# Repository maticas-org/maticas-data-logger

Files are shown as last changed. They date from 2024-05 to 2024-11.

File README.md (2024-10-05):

# Maticas datalogger 🚀⭐️

Want to send measurements back to a server through HTTP or MQTT? This is about it along with:

- The PCB design 🤖.
    - The schematic.
    - The PCB layout.
    - Source files for KiCad.
- 3D design 🗿:
    - The enclosure.
    - The sensor holder, stevenson screen.
- Code for the ESP32 💻.
    - Arduino code.

### ESP32 [Bee-Data-Logger](https://github.com/strid3r21/Bee-Data-Logger) Based 🐝

The ESP32 Bee-Data-Logger based solution is a data logger based on the development from [them](https://github.com/strid3r21/Bee-Data-Logger).

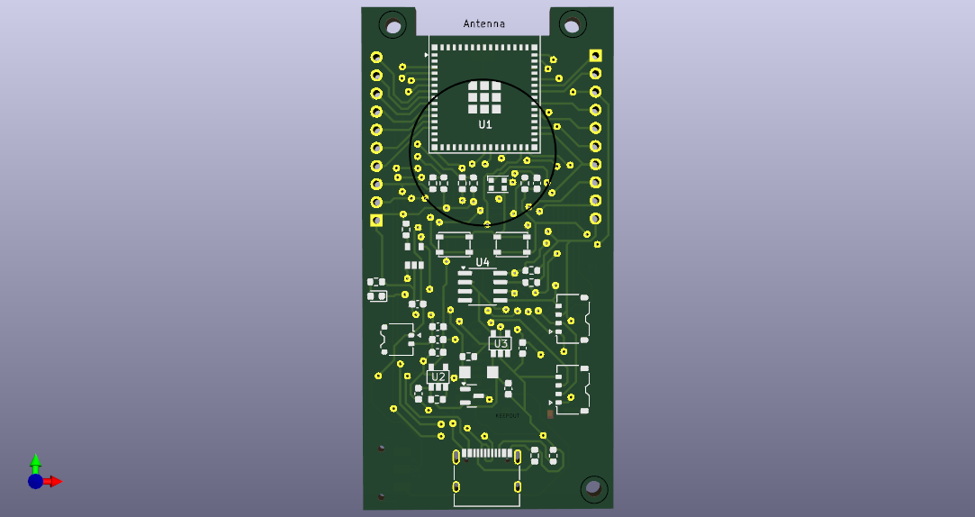
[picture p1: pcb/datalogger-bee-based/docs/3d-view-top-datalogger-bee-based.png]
Bee-Data-Logger


It is intended to be final product, we grabbed the schematic pdf they provided and made a PCB design for it, sharing the KiCad files and the Gerber files, so you can make your own PCB, or have an easier time modifying the design.

If you want to find out more about the ESP32 Bee-Data-Logger based solution, check out the [ESP32 Bee-Data-Logger based PCB design doc](/pcb/datalogger-bee-based/).

### ESP32 Dev Board 🔧

The ESP32 Dev Board is a development board with an ESP32 microcontroller. Intended for prototyping and development, but you could use it for a final product. 

If want to find out more about the ESP32 Dev Board, check out the [ESP32 Dev Board code](/src/arduino/datalogger-esp32-dev-board/) and the [ESP32 Dev Board PCB design doc](/pcb/datalogger-esp32-dev-board/).

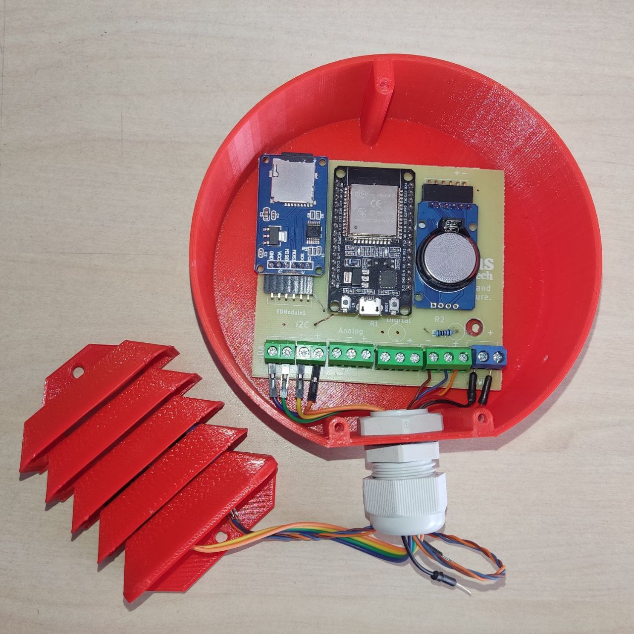
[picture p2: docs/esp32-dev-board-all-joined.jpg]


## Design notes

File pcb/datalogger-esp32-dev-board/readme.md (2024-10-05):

# ESP32 based datalogger development board

This board was designed to be a development board for the ESP32 based datalogger project. It is a simple board with capacity for few sensors and a microSD card slot, along with an RTC. This board is not meant to be a final product, but a development board to help with the development of the datalogger project, does not have a battery management system.

## Features

You can connect:

1. Multiple I2C sensors.
2. 1x Analog sensor.
3. 2x Digital sensor (with pull-up resistor).

And it has:
- MicroSD card slot.
- RTC.

## Product view 
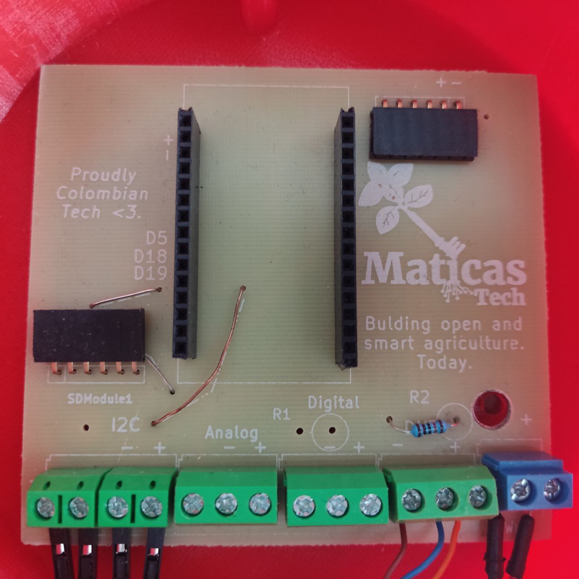
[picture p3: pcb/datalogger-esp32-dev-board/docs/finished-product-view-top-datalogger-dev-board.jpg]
Product view top

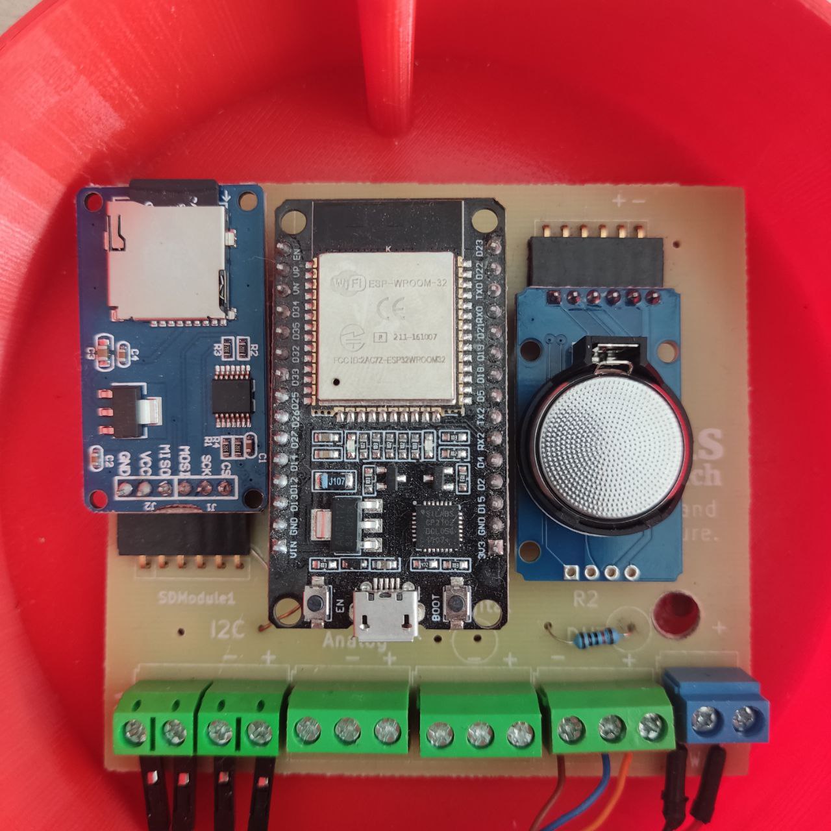
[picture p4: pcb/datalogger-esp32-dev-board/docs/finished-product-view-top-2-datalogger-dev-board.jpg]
Product view top 2


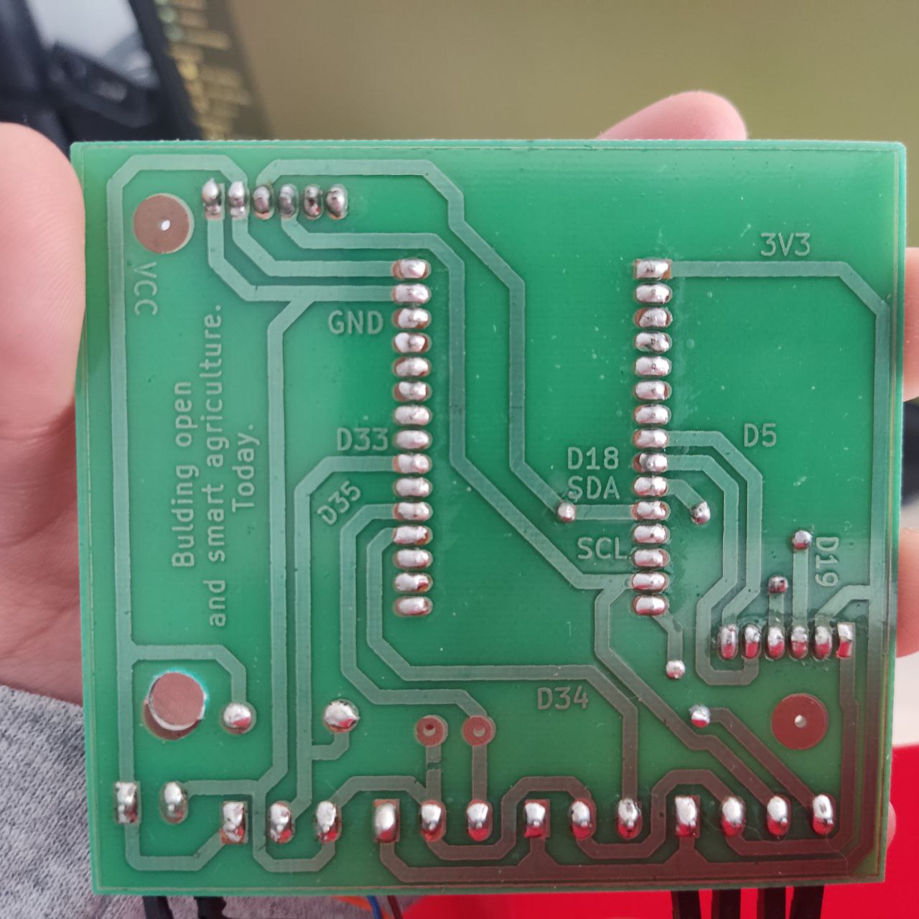
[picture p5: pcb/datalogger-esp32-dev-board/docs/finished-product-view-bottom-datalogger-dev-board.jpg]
Product view bottom


## Schematics
Schematics

## PCB Overview
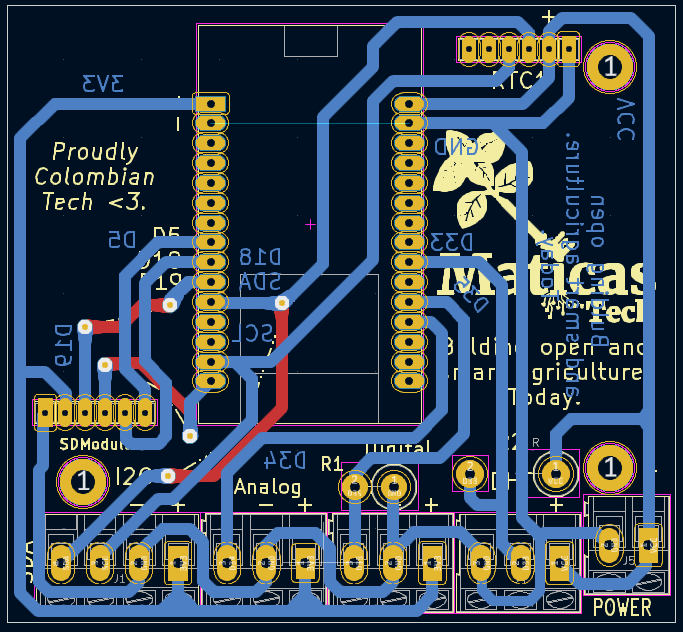
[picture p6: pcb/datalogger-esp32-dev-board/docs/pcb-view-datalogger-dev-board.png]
PCB Overview


## PCB 3D View
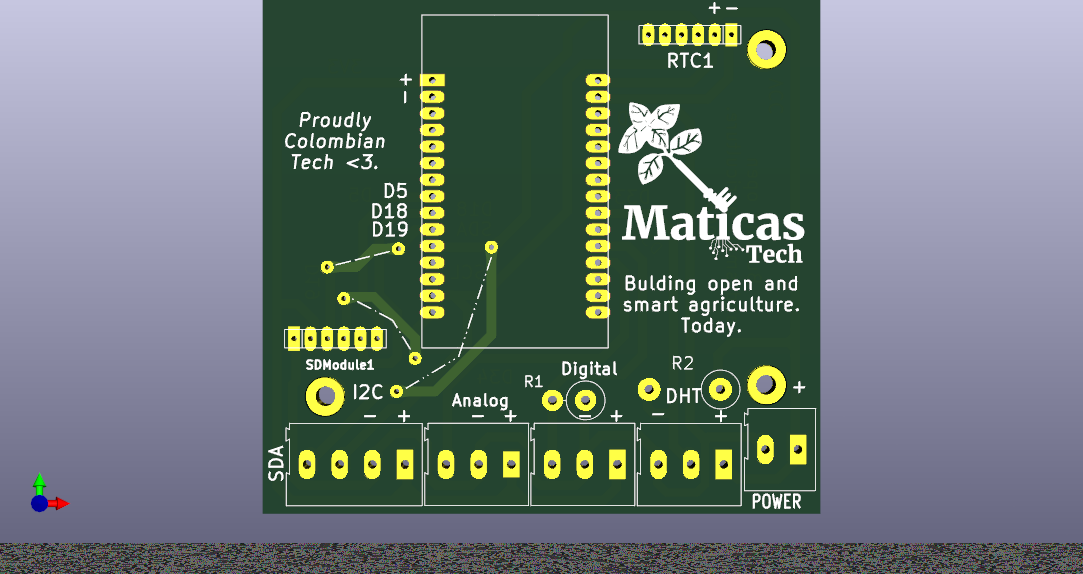
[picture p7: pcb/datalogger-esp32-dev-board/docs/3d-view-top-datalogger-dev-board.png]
PCB 3D View

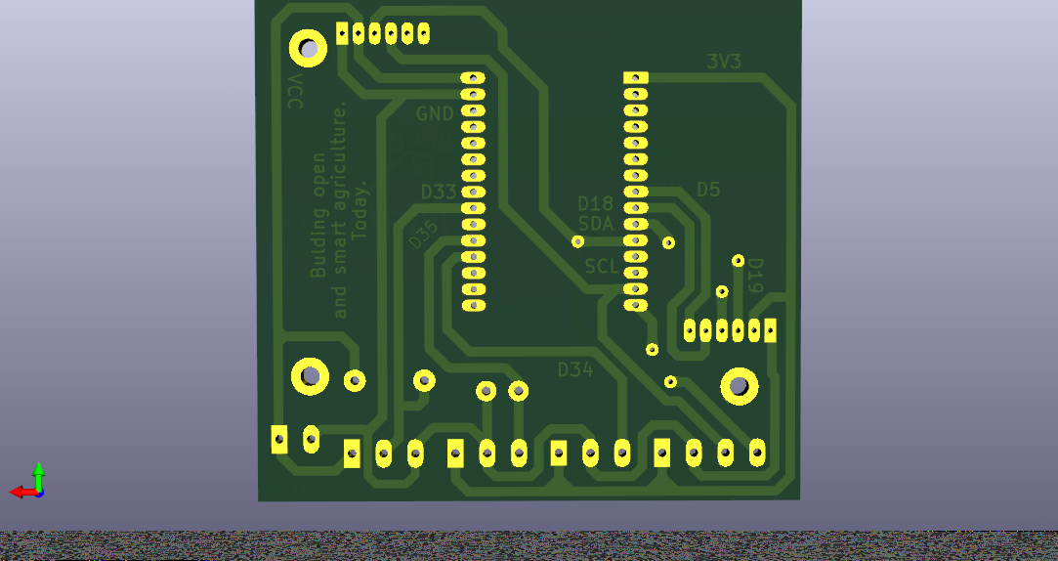
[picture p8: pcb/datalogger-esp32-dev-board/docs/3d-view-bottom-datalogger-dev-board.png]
PCB 3D View


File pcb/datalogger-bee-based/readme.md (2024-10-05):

# This file is inspired on the work of the [Bee-Data-Logger](https://github.com/strid3r21/Bee-Data-Logger) project

Basically we took the schematics they shared and a bit of the layout we get from their [youtube video](https://youtu.be/vbtSqaVAqRw?si=KjJlswMw_XBVi3_l) and we made our own version of the datalogger, sharing the source files from kiCad to make it easier for others to replicate the project.

This PCB replica is undergoing testing and will be updated as soon as we have more information.

Huge thanks to the [Bee-Data-Logger](https://github.com/strid3r21/Bee-Data-Logger) project for sharing their work, it was a great inspiration for us, and a huge help to get started with our own datalogger project. Go check their project out! Give them a star️ ⭐️⭐️⭐! 

Please consider that the latest finished PCB version is [PCB_ESP32.kicad_pro](PCB_ESP32.kicad_pro), this is built on top of Kicad 8.0. So far we don't have code along for this project, so if you are interested in replicating this project, you will need to adapt the code from the [Bee-Data-Logger](https://github.com/strid3r21/Bee-Data-Logger)

## Schematics
Schematics

## PCB Overview
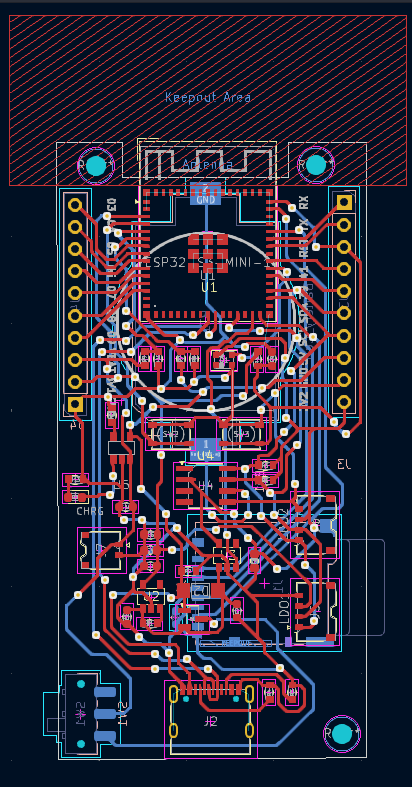
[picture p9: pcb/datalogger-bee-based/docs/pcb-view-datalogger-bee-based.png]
PCB Overview


## PCB 3D View
PCB 3D View
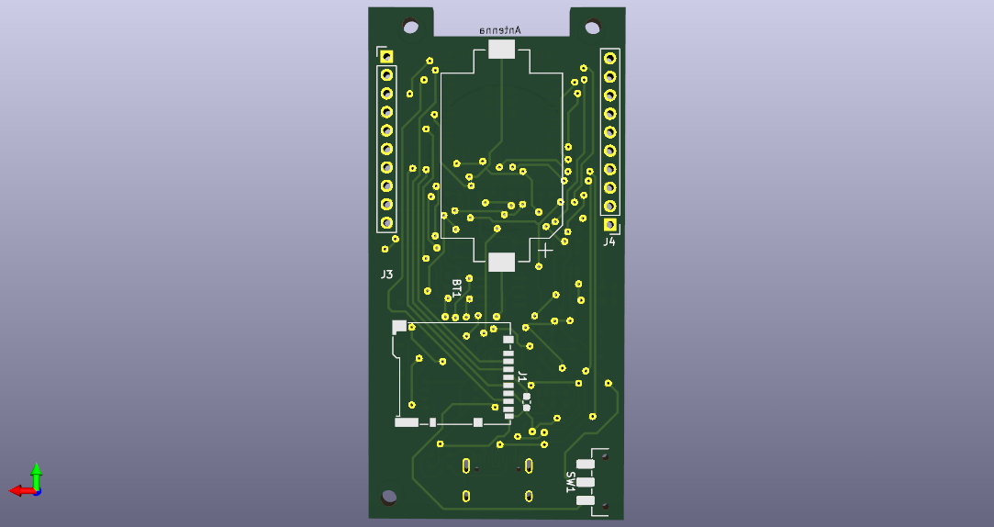
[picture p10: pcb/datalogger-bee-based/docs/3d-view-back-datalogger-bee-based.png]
PCB 3D View


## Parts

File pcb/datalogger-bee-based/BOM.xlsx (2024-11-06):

No. | Quantity | Footprint | Designator |  | Comment | Manufacturer Part | Manufacturer | Supplier Part | Supplier | Primary Category | Secondary Category | Device | Name
1 | 1 | Device_Battery_Cell | BT1 |  | 1060TR |  |  | C238069 |  |  |  | Device_Battery_Cell | Device_Battery_Cell
2 | 7 | Device_C | C1,C3,C4,C5,C6,C7,C10 |  | 10uF |  |  | C96446 |  |  |  | Device_C | Device_C
3 | 2 | Device_C | C8,C9 |  | 1uF |  |  | C15849 |  |  |  | Device_C | Device_C
4 | 1 | LED_WS2812B | D1 |  | WS2812B |  |  | C965555 |  |  |  | LED_WS2812B | LED_WS2812B
5 | 1 | Device_D_Schottky | D2 |  | ss14 |  |  | C2480 |  |  |  | Device_D_Schottky | Device_D_Schottky
6 | 1 | Device_LED | D3 |  | XL-1608SURC-06 |  |  | C965799 |  |  |  | Device_LED | Device_LED
7 | 1 | Connector_Micro_SD_Card | J1 |  | DM3BT-DSF-PEJS |  |  | C597972 |  |  |  | Connector_Micro_SD_Card | Connector_Micro_SD_Card
8 | 1 | Connector_USB_C_Receptacle_USB2.0_16P | J2 |  | U262-161N-4BVC11 |  |  | C319148 |  |  |  | Connector_USB_C_Receptacle_USB2.0_16P | Connector_USB_C_Receptacle_USB2.0_16P
9 | 2 | Connector_Conn_01x10_Socket | J3,J4 |  | Conn_01x10_Socket |  |  | C2894933 |  |  |  | Connector_Conn_01x10_Socket | Connector_Conn_01x10_Socket
10 | 2 | Connector_Conn_01x05_Socket | J5,J6 |  | Conn_01x05_Socket |  |  | C528030 |  |  |  | Connector_Conn_01x05_Socket | Connector_Conn_01x05_Socket
11 | 1 | Connector_Generic_Conn_01x02 | J7 |  | Conn_01x02 |  |  | C202104 |  |  |  | Connector_Generic_Conn_01x02 | Connector_Generic_Conn_01x02
12 | 1 | Transistor_FET_AO3401A | Q1 |  | DMP2045UQ |  |  | C3290014 |  |  |  | Transistor_FET_AO3401A | Transistor_FET_AO3401A
13 | 4 | Device_R | R1,R2,R12,R13 |  | 100K |  |  | C25803 |  |  |  | Device_R | Device_R
14 | 3 | Device_R | R3,R4,R11 |  | 5.1K |  |  | C23186 |  |  |  | Device_R | Device_R
15 | 6 | Device_R | R5,R6,R7,R8,R9,R10 |  | 3.3K |  |  | C22978 |  |  |  | Device_R | Device_R
16 | 1 | Switch_SW_DPDT_x2 | SW1 |  | SW_DPDT_x2 |  |  | C221660 |  |  |  | Switch_SW_DPDT_x2 | Switch_SW_DPDT_x2
17 | 2 | Switch_SW_MEC_5E | SW2,SW3 |  | SW_MEC_5E |  |  | C221896 |  |  |  | Switch_SW_MEC_5E | Switch_SW_MEC_5E
18 | 1 | RF_Module_ESP32-S3-MINI-1 | U1 | BULETM-SMD_ESP32-S3-MINI-1-N8 | ESP32-S3-MINI-1-N8 |  |  | C2913206 |  |  |  | RF_Module_ESP32-S3-MINI-1 | RF_Module_ESP32-S3-MINI-1
19 | 1 | Bee-Data-Logger-library_rt9080-33GJ5 | U2 |  | RT9080-33GJ5 |  |  | C2959864 |  |  |  | Bee-Data-Logger-library_rt9080-33GJ5 | Bee-Data-Logger-library_rt9080-33GJ5
20 | 1 | Bee-Data-Logger-library_rt9080-33GJ5 | U3 |  | RT9080-33GJ5 |  |  | C841192 |  |  |  | Bee-Data-Logger-library_rt9080-33GJ5 | Bee-Data-Logger-library_rt9080-33GJ5
21 | 1 | Timer_RTC_DS3231MZ | U4 |  | DS3231MZ |  |  | C107410 |  |  |  | Timer_RTC_DS3231MZ | Timer_RTC_DS3231MZ
22 | 1 | Bee-Data-Logger-library_MCP73831/2 | U5 |  | MCP73831/2 |  |  | C625597 |  |  |  | Bee-Data-Logger-library_MCP73831/2 | Bee-Data-Logger-library_MCP73831/2

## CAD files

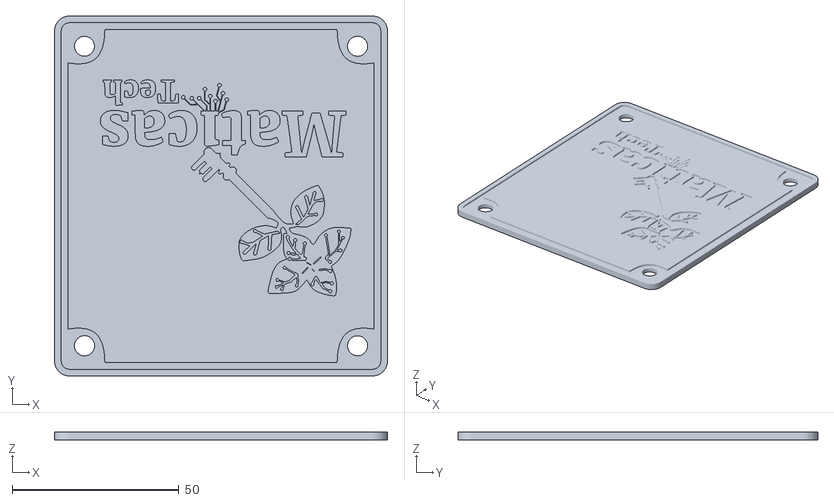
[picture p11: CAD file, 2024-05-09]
3d-printing/box/datalogger-waterproof-box-cap.stl
100.0 x 108.1 x 2.50

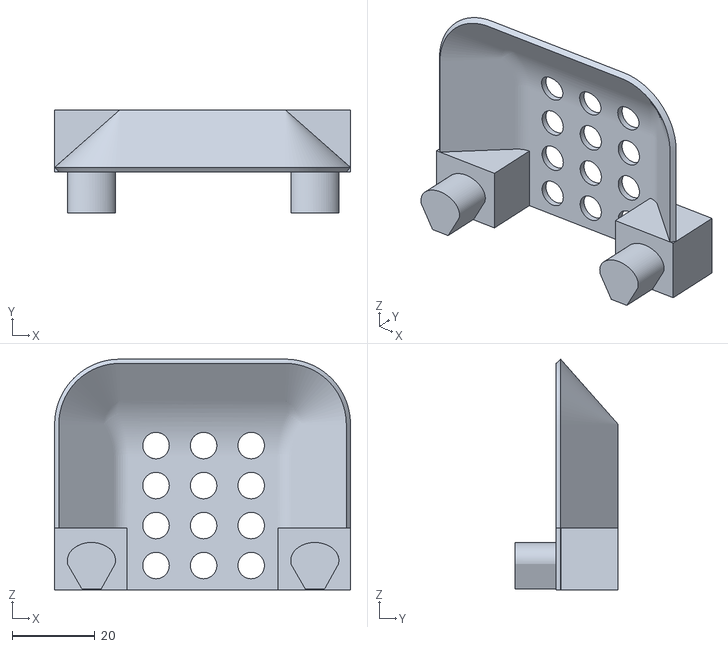
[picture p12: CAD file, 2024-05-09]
3d-printing/stevenson-screen/stevenson-screen-nivel-intermedio-v5.stl
71.5 x 25.0 x 55.8

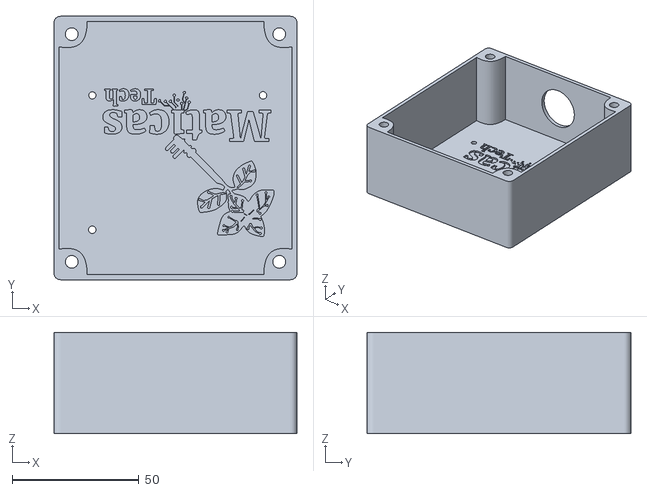
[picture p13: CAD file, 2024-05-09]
3d-printing/box/datalogger-waterproof-box-body.stl
96.0 x 104.1 x 40.0

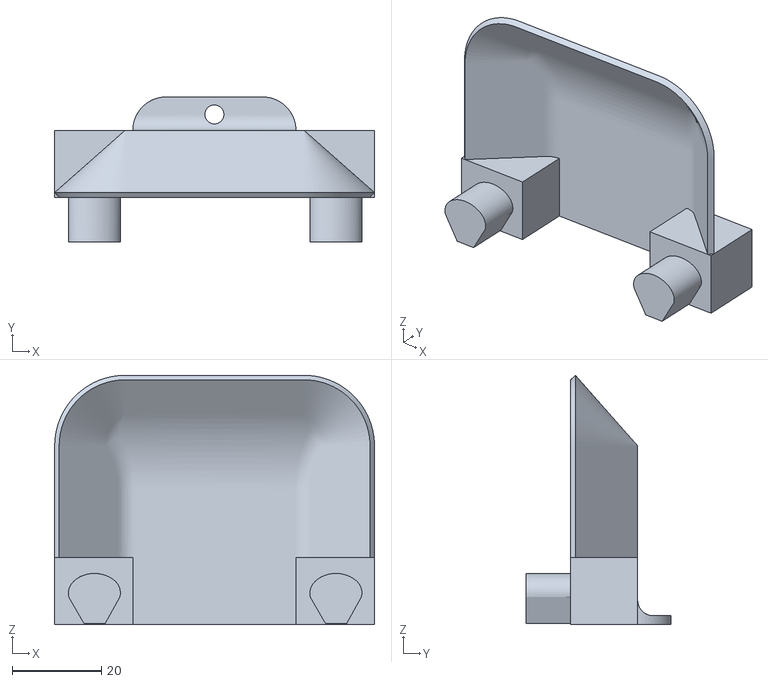
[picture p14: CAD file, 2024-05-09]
3d-printing/stevenson-screen/stevenson-screen-techo-v5.stl
71.5 x 32.5 x 55.8

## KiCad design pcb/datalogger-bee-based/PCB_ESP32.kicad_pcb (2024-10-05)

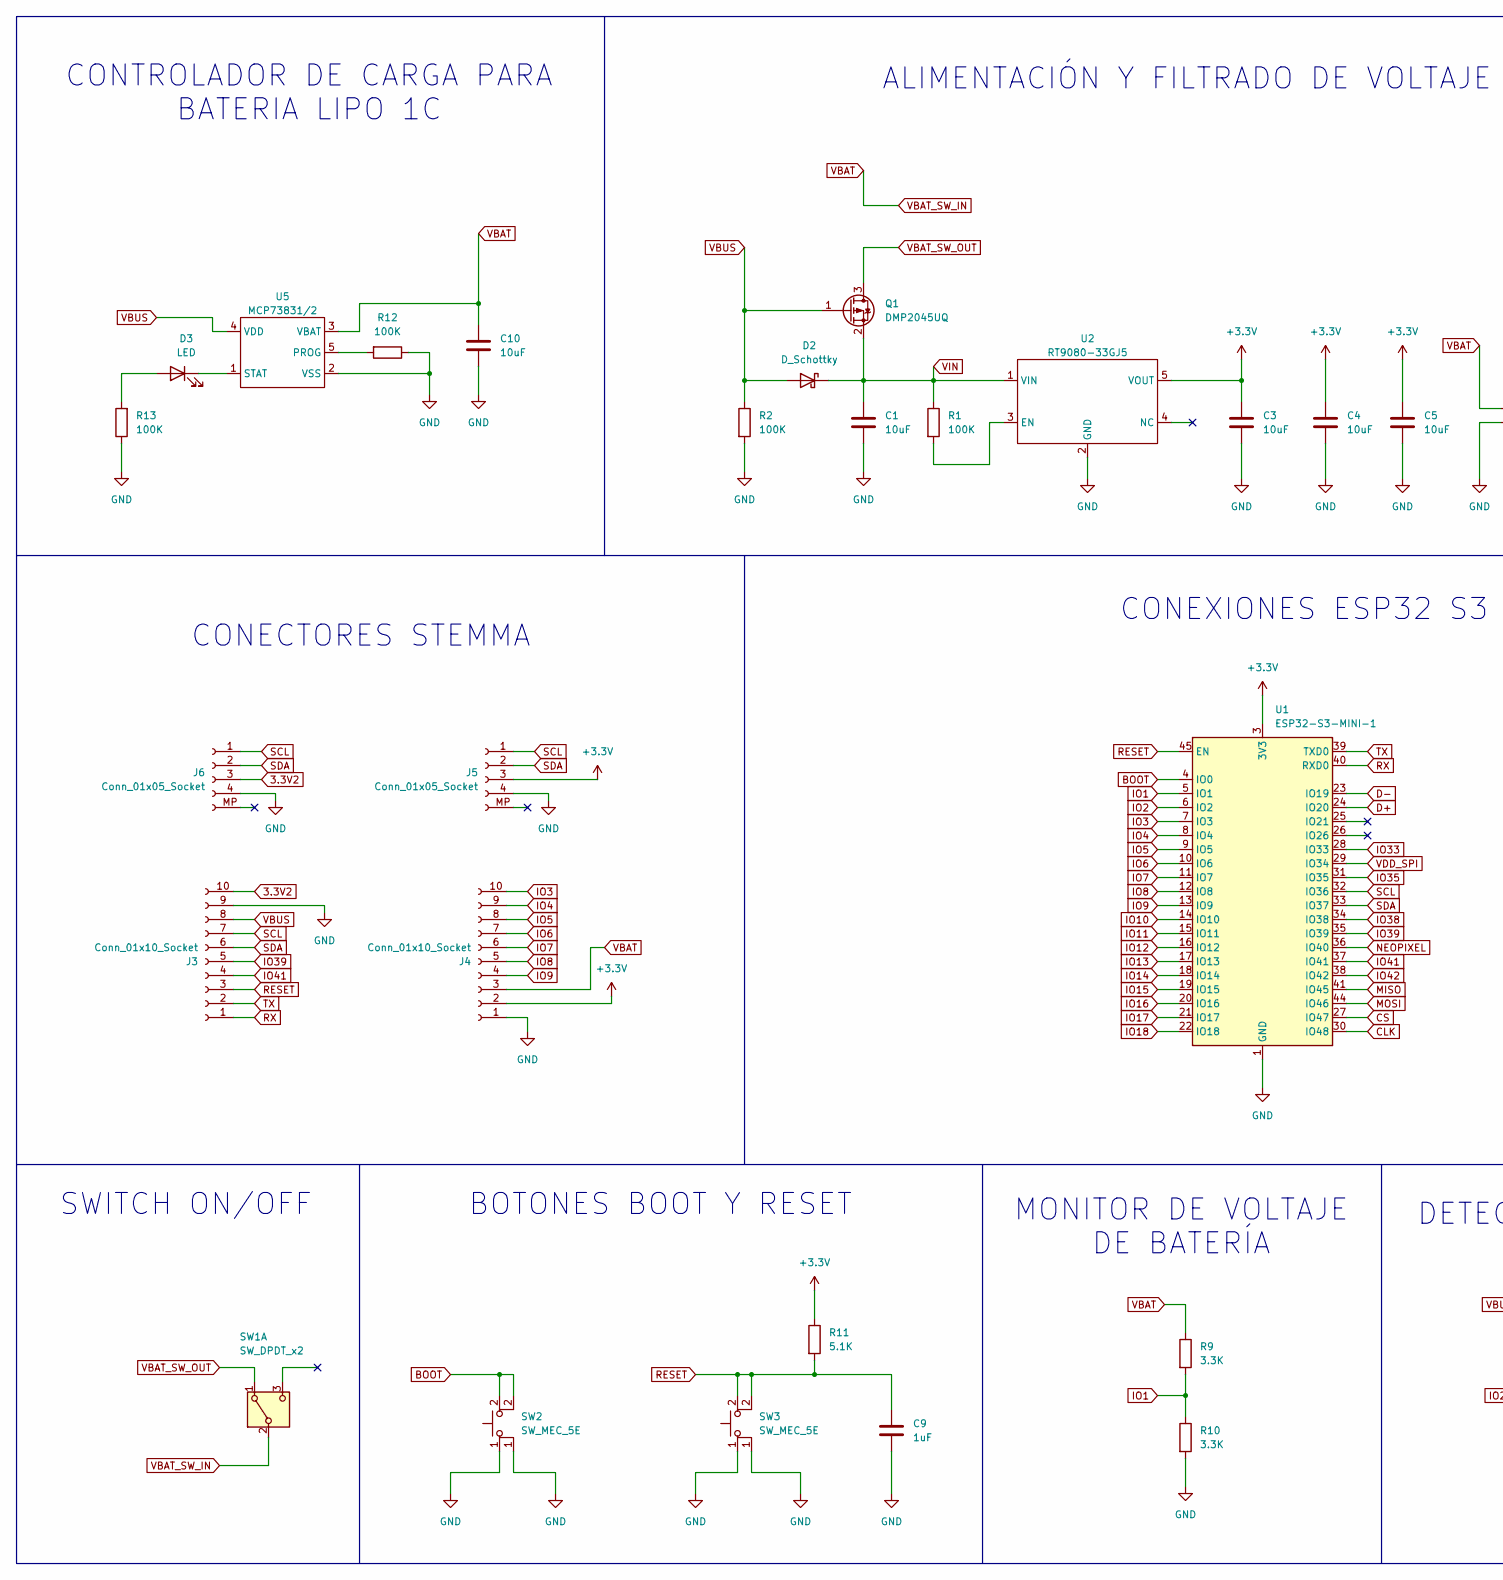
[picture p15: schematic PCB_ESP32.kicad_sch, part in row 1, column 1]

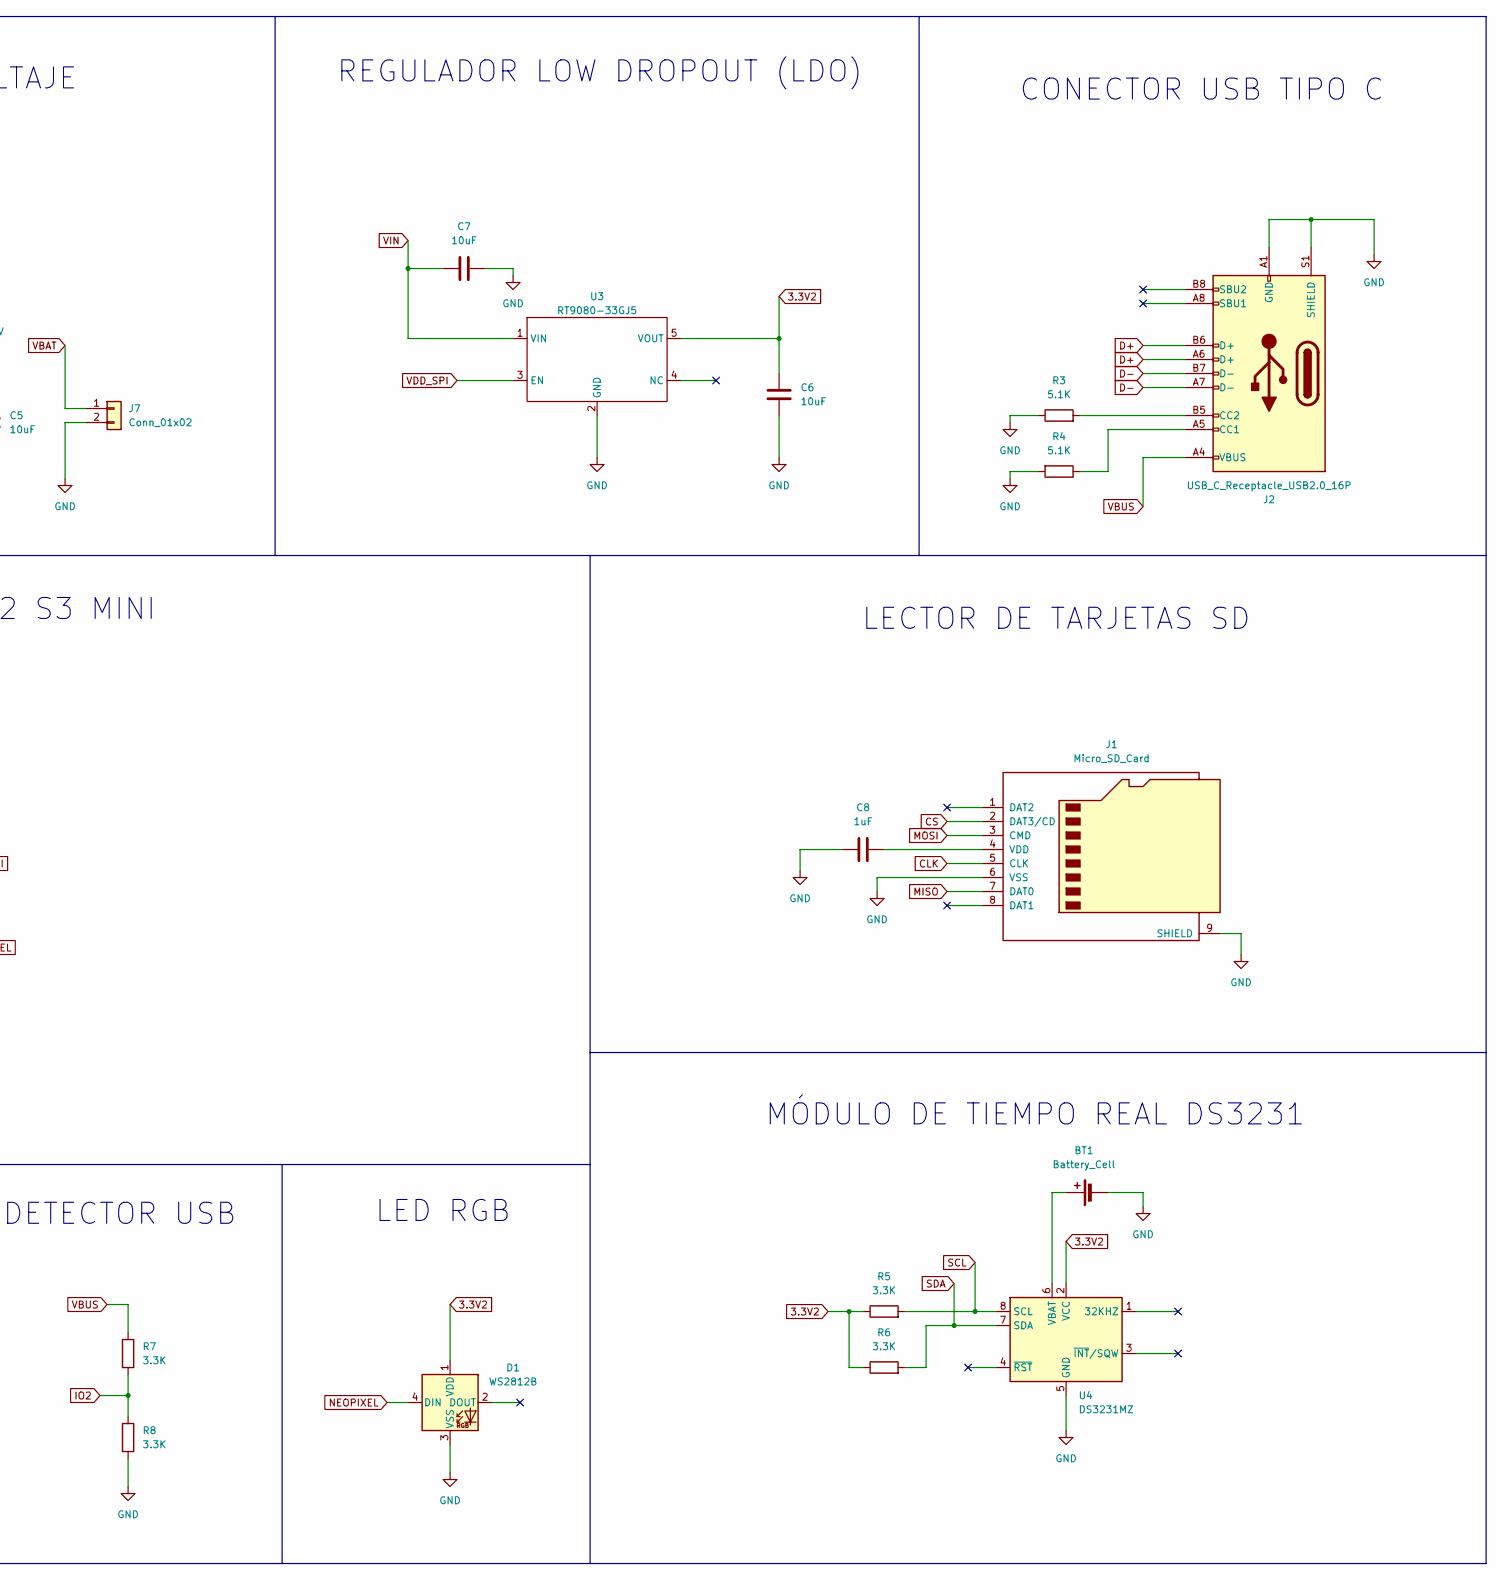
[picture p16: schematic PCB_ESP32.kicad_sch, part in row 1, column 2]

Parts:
BT1: Battery_Cell; BatteryHolder_Keystone_1060_1x2032
C1, C3, C4, C5, C6, C7, C10: 10uF; C_0603_1608Metric
C8, C9: 1uF; C_0603_1608Metric
D1: WS2812B; LED_WS2812B-2020_PLCC4_2.0x2.0mm
D2: D_Schottky; DO-214AC
D3: LED; LED_0603_1608Metric
J1: Micro_SD_Card; microSD_HC_Hirose_DM3BT-DSF-PEJS
J2: USB_C_Receptacle_USB2.0_16P; USB_C_Receptacle_XKB_U262-16XN-4BVC11
J3, J4: Conn_01x10_Socket; PinHeader_1x10_P2.54mm_Vertical
J5, J6: Conn_01x05_Socket; JST_ACH_BM04B-ACHSS-A-GAN-ETF_1x04-1MP_P1.20mm_Vertical
J7: Conn_01x02; JST_ACH_BM02B-ACHSS-GAN-ETF_1x02-1MP_P1.20mm_Vertical
Q1: DMP2045UQ; SOT-23
R1, R2, R12, R13: 100K; R_0603_1608Metric
R3, R4, R11: 5.1K; R_0603_1608Metric
R5, R6, R7, R8, R9, R10: 3.3K; R_0603_1608Metric
SW1: SW_DPDT_x2; SW_SPDT_CK_JS102011SAQN
SW2, SW3: SW_MEC_5E; SW_SPST_PTS810
U1: ESP32-S3-MINI-1; ESP32-S2-MINI-1
U2, U3: RT9080-33GJ5; TSOT-23-5
U4: DS3231MZ; SOIC-8_3.9x4.9mm_P1.27mm
U5: MCP73831/2; SOT-23-5

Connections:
3.3V2: C6.1, D1.1 (VDD), J3.10, J6.3, R5.1, R6.1, U3.5 (VOUT), U4.2 (VCC)
+3.3V: C3.1, C4.1, C5.1, J4.2, J5.3, R11.1, U1.3 (3V3), U2.5 (VOUT)
BOOT: SW2.2, U1.4 (IO0)
CLK: J1.5 (CLK), U1.30 (IO48)
CS: J1.2 (DAT3/CD), U1.27 (IO47)
D+: J2.A6 (D+), J2.B6 (D+), U1.24 (IO20)
D-: J2.A7 (D-), J2.B7 (D-), U1.23 (IO19)
GND: BT1.2 (-), C1.2, C3.2, C4.2, C5.2, C6.2, C7.2, C8.1, C9.2, C10.2, D1.3 (VSS), J1.6 (VSS), J1.9 (SHIELD), J2.A1 (GND), J2.A12 (GND), J2.B1 (GND), J2.B12 (GND), J2.S1 (SHIELD), J3.9, J4.1, J5.4, J6.4, J7.2, R2.2, R3.1, R4.2, R8.2, R10.2, R12.1, R13.1, SW2.1, SW3.1, U1.1 (GND), U1.2 (GND), U1.42 (GND), U1.43 (GND), U1.46 (GND), U1.47 (GND), U1.48 (GND), U1.49 (GND), U1.50 (GND), U1.51 (GND), U1.52 (GND), U1.53 (GND), U1.54 (GND), U1.55 (GND), U1.56 (GND), U1.57 (GND), U1.58 (GND), U1.59 (GND), U1.60 (GND), U1.61 (GND), U1.62 (GND), U1.63 (GND), U1.64 (GND), U1.65 (GND), U2.2 (GND), U3.2 (GND), U4.5 (GND), U5.2 (VSS)
IO1: R9.2, R10.1, U1.5 (IO1)
IO2: R7.2, R8.1, U1.6 (IO2)
IO3: J4.10, U1.7 (IO3)
IO4: J4.9, U1.8 (IO4)
IO5: J4.8, U1.9 (IO5)
IO6: J4.7, U1.10 (IO6)
IO7: J4.6, U1.11 (IO7)
IO8: J4.5, U1.12 (IO8)
IO9: J4.4, U1.13 (IO9)
IO10: U1.14 (IO10)
IO11: U1.15 (IO11)
IO12: U1.16 (IO12)
IO13: U1.17 (IO13)
IO14: U1.18 (IO14)
IO15: U1.19 (IO15)
IO16: U1.20 (IO16)
IO17: U1.21 (IO17)
IO18: U1.22 (IO18)
IO33: U1.28 (IO33)
IO35: U1.31 (IO35)
IO38: U1.34 (IO38)
IO39: J3.5, U1.35 (IO39)
IO41: J3.4, U1.37 (IO41)
IO42: U1.38 (IO42)
MISO: J1.7 (DAT0), U1.41 (IO45)
MOSI: J1.3 (CMD), U1.44 (IO46)
NEOPIXEL: D1.4 (DIN), U1.36 (IO40)
unnamed: BT1.1 (+), U4.6 (VBAT)
unnamed: D3.2 (A), R13.2
unnamed: D3.1 (K), U5.1 (STAT)
unnamed: C8.2, J1.4 (VDD)
unnamed: J2.A5 (CC1), R4.1
unnamed: J2.B5 (CC2), R3.2
unnamed: R1.2, U2.3 (EN)
unnamed: R12.2, U5.5 (PROG)
RESET: C9.1, J3.3, R11.2, SW3.2, U1.45 (EN)
RX: J3.1, U1.40 (RXD0)
SCL: J3.7, J5.1, J6.1, R5.2, U1.32 (IO36), U4.8 (SCL)
SDA: J3.6, J5.2, J6.2, R6.2, U1.33 (IO37), U4.7 (SDA)
TX: J3.2, U1.39 (TXD0)
VBAT: C10.1, J4.3, J7.1, R9.1, SW1.2 (B), U5.3 (VBAT)
VBAT_SW_OUT: Q1.3 (D), SW1.1 (A)
VBUS: D2.2 (A), J2.A4 (VBUS), J2.A9 (VBUS), J2.B4 (VBUS), J2.B9 (VBUS), J3.8, Q1.1 (G), R2.1, R7.1, U5.4 (VDD)
VDD_SPI: U1.29 (IO34), U3.3 (EN)
VIN: C1.1, C7.1, D2.1 (K), Q1.2 (S), R1.1, U2.1 (VIN), U3.1 (VIN)

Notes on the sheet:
LED RGB
CONEXIONES ESP32 S3 MINI
CONECTORES STEMMA
MONITOR DE VOLTAJE DE BATERÍA
LECTOR DE TARJETAS SD
SWITCH ON/OFF
ALIMENTACIÓN Y FILTRADO DE VOLTAJE
BOTONES BOOT Y RESET
DETECTOR USB
MÓDULO DE TIEMPO REAL DS3231
CONECTOR USB TIPO C
CONTROLADOR DE CARGA PARA BATERIA LIPO 1C
REGULADOR LOW DROPOUT (LDO)

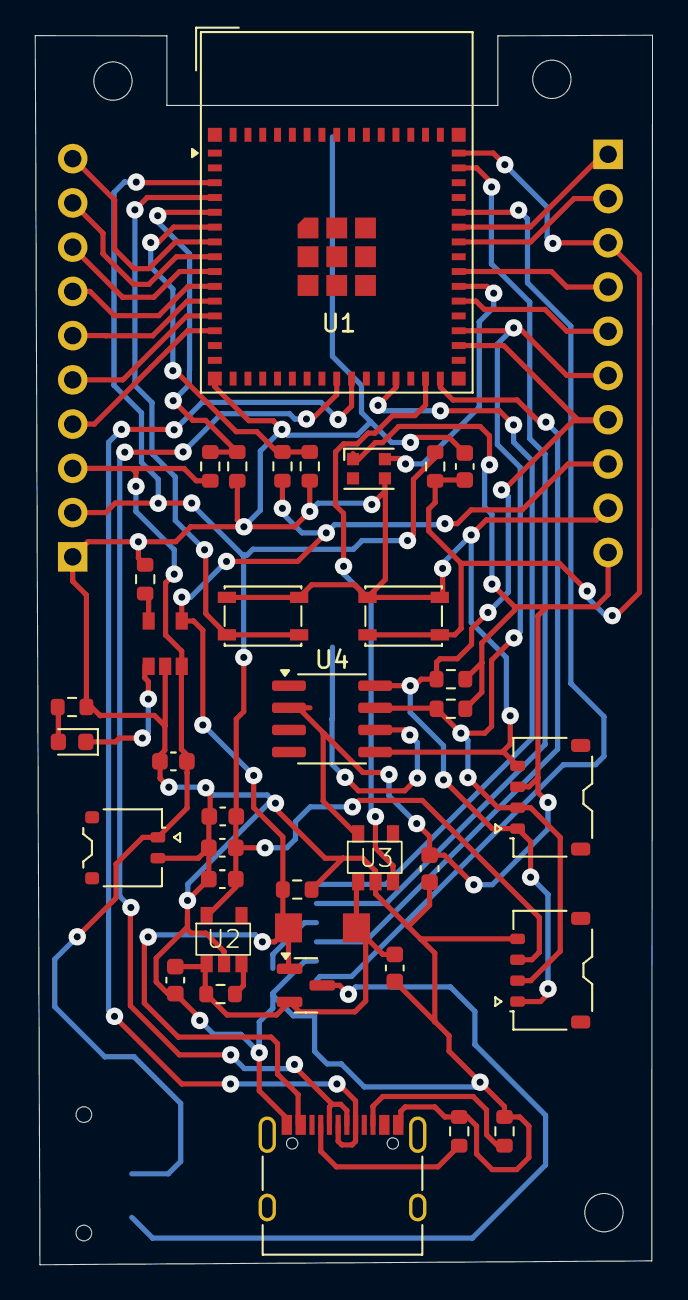
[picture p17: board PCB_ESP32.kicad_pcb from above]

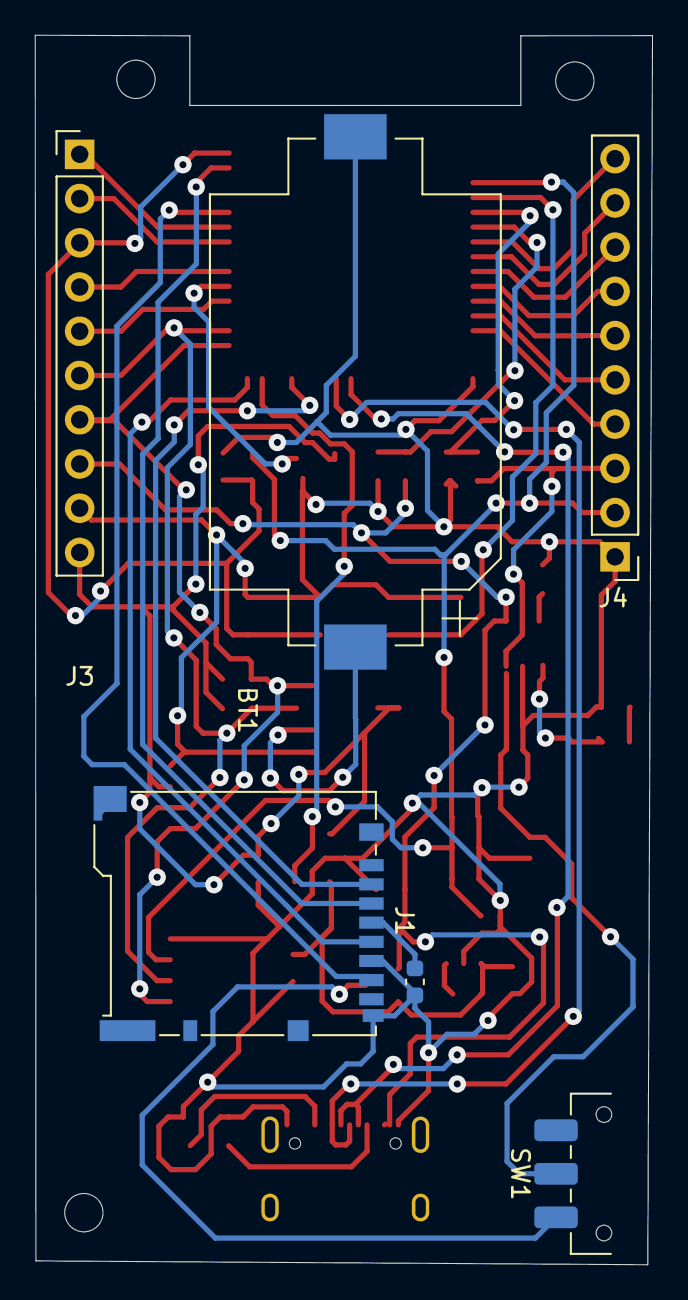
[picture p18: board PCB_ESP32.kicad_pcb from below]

Board: 2 copper layers, 35.4 x 70.6 mm, 42 parts (6 on the bottom side), 40 nets.

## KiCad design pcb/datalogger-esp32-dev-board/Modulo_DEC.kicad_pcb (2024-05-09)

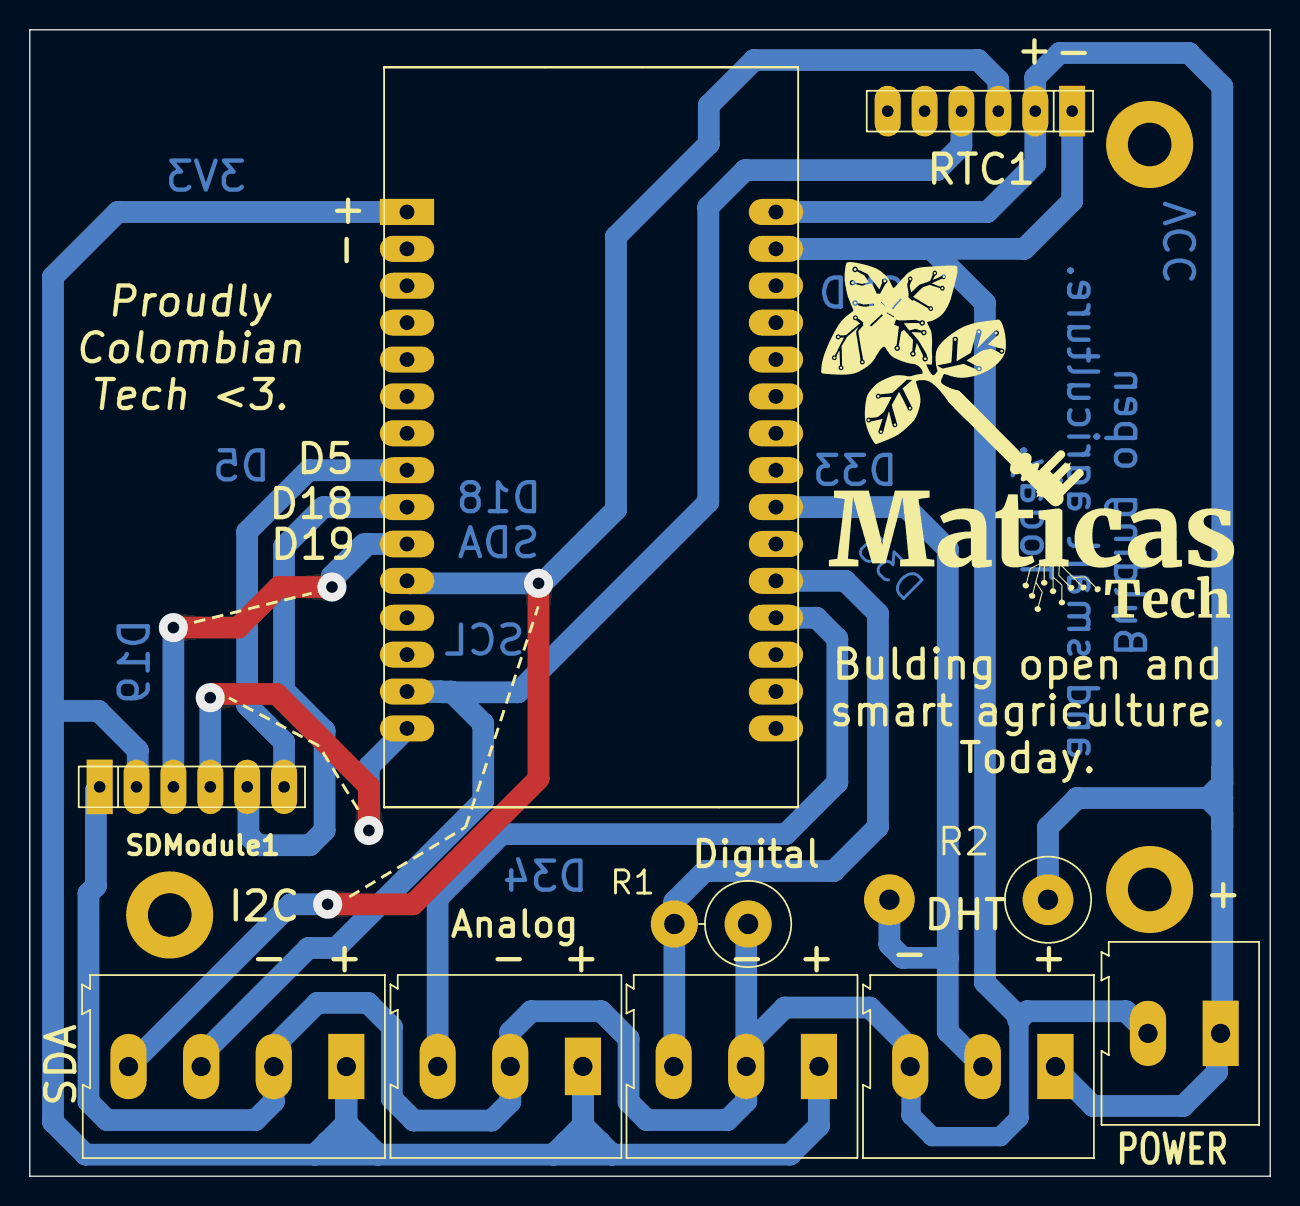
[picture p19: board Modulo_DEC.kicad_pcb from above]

Board: 2 copper layers, 85.4 x 78.9 mm, 13 parts (0 on the bottom side), 12 nets.

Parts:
H1, H2, H3: MountingHole; MountingHole_3mm_Pad
J1: Screw_Terminal_01x04; TerminalBlock_Altech_AK300-4_P5.00mm
J2, J3, J4: Screw_Terminal_01x03; TerminalBlock_Altech_AK300-3_P5.00mm
J5: Screw_Terminal_01x02; TerminalBlock_Altech_AK300-2_P5.00mm
R1, R2: R; R_Axial_DIN0614_L14.3mm_D5.7mm_P5.08mm_Vertical
RTC1: R_Array_SIP6
SDModule1: R_Network_Dividers_x04_SIP; R_Array_SIP6
U1: ESP32-DEVKIT-V1; MODULE_ESP32_DEVKIT_V1

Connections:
3V3: J1.1, J2.1, J3.1, SDModule1.2 (R1), U1.1 (3V3)
D5: SDModule1.6 (COM2), U1.8 (D5)
D18: SDModule1.5 (R4), U1.9 (D18)
D19: SDModule1.3 (R2), U1.10 (D19)
D23: SDModule1.4 (R3), U1.15 (D23)
D33: J4.2, R2.2, U1.22 (D33)
D34: J2.3, U1.19 (D34)
D35: J3.3, R1.2, U1.20 (D35)
GND: J1.2, J2.2, J3.2, J4.3, J5.2, R1.1, RTC1.1 (COM1), SDModule1.1 (COM1), U1.2 (GND), U1.29 (GND)
SCL: J1.3, RTC1.4 (R3), U1.14 (D22)
SDA: J1.4, RTC1.3 (R2), U1.11 (D21)
VCC: J4.1, J5.1, R2.1, RTC1.2 (R1), U1.30 (VIN)

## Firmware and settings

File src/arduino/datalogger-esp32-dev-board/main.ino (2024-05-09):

#ifndef EXT_IMPORTS
#define EXT_IMPORTS
  #include "FS.h"
  #include "SD.h"
  #include "SPI.h"
  #include "WiFi.h"
  #include "I2C_RTC.h"
  #include <Arduino.h>
  #include <ArduinoHttpClient.h>
#endif


#include "EventManager.h"
#include "TimeEventManager.h"
#include "ConnectionEventManager.h"

#include "CustomUtils.h"
#include "secrets.h"
#include "SensorAdapters.h"
#include "SensorsMicroService.h"

//SD card
bool sdCardInitialized = false;

//time in seconds
#define timeEventManagerFrequency 5              //5 seconds
#define sensorsMicroServiceFrequency 10*1        //2 minutes
#define connectionEventManagerFrequency 41*1    //10 minutes
#define sdStoreFrequency 60*2                    //11 minutes
#define sdLoadFrequency 60*1                     //12 minutes
#define LED 2

void updateEventManager(EventManager &eventManager, unsigned long &previousEventMillis, unsigned long &currentMillis, unsigned long eventFrequency);
void sendPendingAndStoreExcessEvents(ConnectionEventManager &connectioneventmanager, TimeEventManager &timeeventmanager);
void loadAndSendEvents(ConnectionEventManager &connectionEventManager, bool fromNewestToOldest = true);

void setup() {

  //initialize the serial port, the i2c bus, the spi bus
  Serial.begin(9600);
  delay(250);
  Wire.begin();
  delay(250);
  SPI.begin(SCK, MISO, MOSI, CS);
  delay(250);

  //initialize the LED
  pinMode(LED, OUTPUT);
  digitalWrite(LED, HIGH);
  delay(1000);
  digitalWrite(LED, LOW);

  // start the SD card
  if(!SD.begin()){
      Serial.println("Card Mount Failed");
  }else{
      Serial.println("Card Mount Success");
      sdCardInitialized = true;
  }

  showAditionalSDCardInfo(SD);
}

void loop() {

  delay(100);
  TimeEventManager timeEventManager = TimeEventManager(timeEventManagerFrequency);
  ConnectionEventManager connectionEventManager;
  SensorsMicroService sensorsMicroService = SensorsMicroService();
  DHTAdapter dhtAdapter = DHTAdapter();
  LuxAndDLIAdapter luxAndDLIAdapter = LuxAndDLIAdapter(connectionEventManagerFrequency);

  sensorsMicroService.AddSensor(&dhtAdapter);
  sensorsMicroService.AddSensor(&luxAndDLIAdapter);

  timeEventManager.subscribe(&sensorsMicroService);
  sensorsMicroService.subscribe(&connectionEventManager);
  delay(100);
  logMemoryUsage();
  connectionEventManager.main();
  logMemoryUsage();

  unsigned long previousTimeEventMillis = 0;
  unsigned long previousConnectionEventMillis = 0;
  unsigned long previousSensorsMicroServiceMillis = 0;
  unsigned long sdStoreMillis = 0;
  unsigned long sdLoadMillis = 0;
  unsigned long currentMillis = millis();

  while (true) {
    currentMillis = millis();
    
    //update the time
    updateEventManager(timeEventManager, previousTimeEventMillis, currentMillis, timeEventManagerFrequency);
    
    //update the connection - this tries to connect to the wifi and check if the connection
    //is still alive
    updateEventManager(connectionEventManager, previousConnectionEventMillis, currentMillis, connectionEventManagerFrequency);

    //update the time
    updateEventManager(timeEventManager, previousTimeEventMillis, currentMillis, timeEventManagerFrequency);

    //update the measurements from sensors - this tries to get the measurements from
    //the sensors and notify the subscribers
    updateEventManager(sensorsMicroService, previousSensorsMicroServiceMillis, currentMillis, sensorsMicroServiceFrequency);

    //update the time
    updateEventManager(timeEventManager, previousTimeEventMillis, currentMillis, timeEventManagerFrequency);

    //send pending events and store excess events
    sendPendingAndStoreExcessEvents(connectionEventManager, timeEventManager);

    //load and send events from the SD card
    loadAndSendEvents(connectionEventManager);

    //show memory usage
    logMemoryUsage();
    delay(2500);
  }

}



/*
* Update the event manager
*/
void updateEventManager(EventManager &eventManager,
                        unsigned long &previousEventMillis,
                        unsigned long &currentMillis,
                        unsigned long eventFrequency) {
  if (currentMillis - previousEventMillis >= eventFrequency * 1000) {
    eventManager.notify();
    previousEventMillis = currentMillis;
  }
  currentMillis = millis();
}

void sendPendingAndStoreExcessEvents(ConnectionEventManager &connectionEventManager, 
                                     TimeEventManager &timeEventManager){
  
  String epoch = String(abs(timeEventManager.getEpoch()));
  String fileName = "/" + epoch + ".txt";

  // try to send any pending events
  connectionEventManager.sendMemAllocatedData();

  // store excess pending events in the SD card
  Event excessEvents[MAX_EVENTS_PER_FILE];
  bool availableData = connectionEventManager.returnExcessEvents(excessEvents, MAX_EVENTS_PER_FILE);
  if (availableData) {
    storeEvents(SD, excessEvents, MAX_EVENTS_PER_FILE, fileName.c_str());
  }
}

void loadAndSendEvents(ConnectionEventManager &connectionEventManager, 
                       bool fromNewestToOldest) {
  Event loadedEvents[MAX_EVENTS_PER_FILE];
  String filename = "/" + findFileByDate(SD, "/", fromNewestToOldest);
  bool loadedData = loadEvents(SD, loadedEvents, MAX_EVENTS_PER_FILE, filename.c_str());

  if (loadedData) {
    bool allSent = connectionEventManager.updateFromLoadedEvents(loadedEvents, MAX_EVENTS_PER_FILE);
    //if all events were sent, delete the file, otherwise store the remaining events
    if (allSent) {
      deleteFile(SD, filename.c_str());
    }else{
      storeEvents(SD, loadedEvents, MAX_EVENTS_PER_FILE, filename.c_str());
    }
  }
}

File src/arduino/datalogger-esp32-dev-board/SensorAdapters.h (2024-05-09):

#include "DHT.h"
#include <BH1750.h>

#include "secrets.h"
#include "Event.h"
#include "Adapter.h"
#include "CustomUtils.h"

#define DHTPIN 33
#define DHTTYPE DHT11
#define MAX_RETRIES 5

DHT dht = DHT(DHTPIN, DHTTYPE);
BH1750 lightMeter;
const double lux2parConversionFactor = 0.0185; // Conversion factor from lux to PAR

//--------------------HELPER FUNCTIONS--------------------

float average(float values[], int size)
{
    if (size == 0)
    {
        return 0;
    }

    float sum = 0;
    for (int i = 0; i < size; i++)
    {
        sum += values[i];
    }
    return sum / size;
}

bool isvalid(float value)
{
    return !isnan(value) && !isinf(value) && value >= 0;
}

/***************** Vapour Pressur Deficit in kPa ********************/
float calculateSaturationVaporPressure(float temperature)
{
    return 0.6108 * exp((17.27 * temperature) / (temperature + 237.3));
}

float calculateVPD(float temperature, float relativeHumidity)
{
    float saturationVaporPressure = calculateSaturationVaporPressure(temperature);
    return (1.0 - (relativeHumidity / 100.0)) * saturationVaporPressure; // kPa
}

/***************** Dew point in °C ********************/
// Magnus coefficients
const float a = 17.625;
const float b = 243.04;

// Function to calculate the Magnus-Tetens intermediate value alpha
float calculateAlpha(float temperature, float relativeHumidity)
{
    return log(relativeHumidity / 100.0) + (a * temperature) / (b + temperature);
}

// Function to calculate Dew Point (Ts) using the Magnus-Tetens formula
float calculateDewPoint(float temperature, float relativeHumidity)
{
    float alpha = calculateAlpha(temperature, relativeHumidity);
    return (b * alpha) / (a - alpha);
}

//--------------------ADAPTERS--------------------
class DHTAdapter : public Adapter
{
private:
    Event (*specificRequestFunc)() = nullptr;
    int maxRetries;
    int retryDelay;
    long int lastRequestTimestamp = -1;

public:
    DHTAdapter(int maxRetries = 5, int retryDelay = 2100) : Adapter()
    {
        dht.begin();
        this->maxRetries = maxRetries;
        this->retryDelay = retryDelay;
    }

    Event request(Event timeEvent)
    {
        Serial.println("DHTAdapter handling request...");
        return specificRequest(timeEvent);
    }

    Event specificRequest(Event timeEvent)
    {
        // Run specific request function if it is set
        // Otherwise, run the default request function
        if (specificRequestFunc != nullptr)
        {
            return specificRequestFunc();
        }
        else
        {
            return default_request(timeEvent);
        }
    }

    Event default_request(Event timeEvent)
    {
        float temperatureArray[maxRetries];
        float humidityArray[maxRetries];

        try
        {
            dht.begin();
            int validReadings = 0;

            for (int i = 0; i < maxRetries; i++)
            {
                float humidity = dht.readHumidity();
                float temperature = dht.readTemperature();
                Serial.println("Humidity: " + String(humidity) + " %\t Temperature: " + String(temperature) + " *C ");

                if (isvalid(humidity) && isvalid(temperature))
                {
                    temperatureArray[i] = temperature;
                    humidityArray[i] = humidity;
                    validReadings++;
                }

                delay(retryDelay);
            }

            if (validReadings == 0)
            {
                Serial.println("No valid data.");
                return Event(MEASUREMENT_EVENT, INTERNAL_SERVER_ERROR, "", "No valid data");
            }

            float temperature = average(temperatureArray, validReadings);
            float humidity = average(humidityArray, validReadings);
            float vpd = calculateVPD(temperature, humidity);
            float dewPoint = calculateDewPoint(temperature, humidity);

            // Format data in JSON-like string as a list of measurements
            const String timestamp = String(timeEvent.getTimestamp());
            const String data1 = "{\"variable\": " + TEMPERATURE_UIID + ", \"value\": " + String(temperature) + ", \"crop\": " + CROP_UIID + ", \"datetime\": \"" + timestamp + "\"}";
            const String data2 = "{\"variable\": " + HUMIDITY_UIID + ", \"value\": " + String(humidity) + ", \"crop\": " + CROP_UIID + ", \"datetime\": \"" + timestamp + "\"}";
            const String data3 = "{\"variable\": " + VPD_UIID + ", \"value\": " + String(vpd) + ", \"crop\": " + CROP_UIID + ", \"datetime\": \"" + timestamp + "\"}";
            const String data4 = "{\"variable\": " + DEWPOINT_UIID + ", \"value\": " + String(dewPoint) + ", \"crop\": " + CROP_UIID + ", \"datetime\": \"" + timestamp + "\"}";
            const String data = "[" + data1 + ", " + data2 + ", " + data3 + ", " + data4 + "]";
            return Event(MEASUREMENT_EVENT, OK_STATUS, timestamp, data);
        }
        catch (std::exception e)
        {
            // Print the exception and the message
            Serial.println(e.what());
            return Event(MEASUREMENT_EVENT, INTERNAL_SERVER_ERROR, "", "DHT sensor not found");
        }
    }
};

/*
 * Adapter for the BH1750 light sensor
 */

class LuxAndDLIAdapter : public Adapter
{

private:
    Event (*specificRequestFunc)() = nullptr;
    int maxRetries;
    int retryDelay;
    int measurement_interval; // in seconds

    // used for DLI calculation
    DateTime prevDateTime = DateTime(0, 0, 0, 0, 0, 0);
    double lastLux = 0;
    double dailyLightSum = 0;
    long int lastRequestTimestamp = -1;
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

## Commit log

2024-05-09 first commit, added the PCB files, working source code and .stl files of the box
    [BOX.0001.ipt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]
2024-10-05 add, added bee datalogger replication work
    [PCB_ESP32.kicad_pcb, PCB_ESP32.kicad_sch, PCB_ESP32_v2.kicad_pcb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]
2024-10-05 update, added documentation for esp32 dev board, and renamed the src code folder for esp32 dev board to be more easy to understand code structure
2024-11-06 update, PCB reviewed and sent to production, final testing remains to be done, added BOM and pos file, along with the outputs.zip used for fabrication
    [BOM.xlsx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]
